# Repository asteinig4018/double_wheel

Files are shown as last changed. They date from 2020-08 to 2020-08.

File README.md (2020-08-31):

# Double Wheel Robot
A completely 3D printed robotics platform with a unique design. 

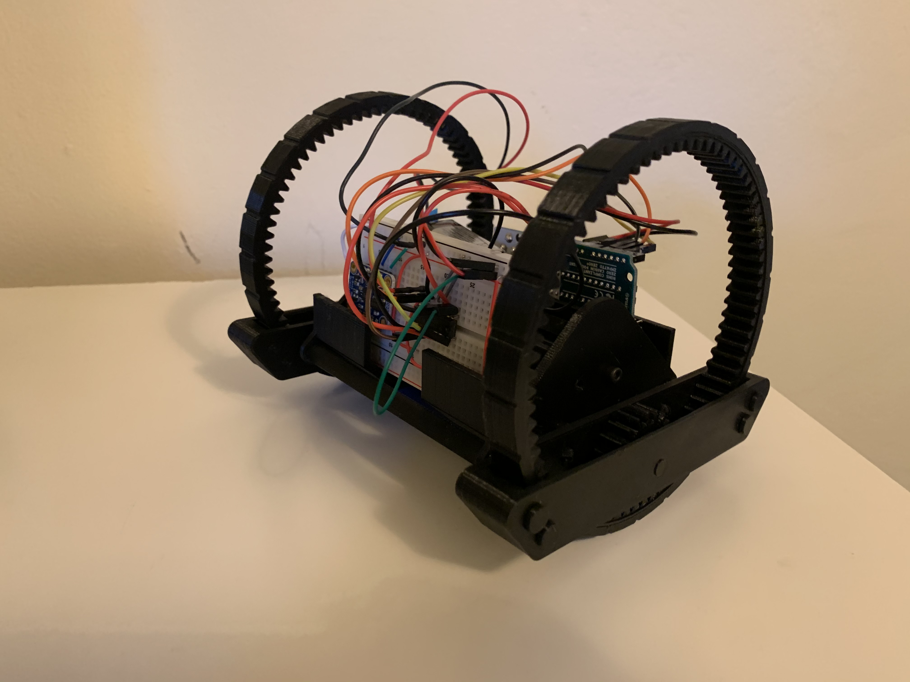
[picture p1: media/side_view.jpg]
Side View V1


## Motivation
This project builds upon the snap fit and gear testing done with my Gearbox Mk1 Project. 
The idea was to create a completely 3D printed platform to experiment with PID control on Arduino in a unique robot body. The large wheels don't provide a whole lot of benefit other than looking unique. 

## Features

### Wheels
The large wheels have 5 points of contact:
- The gear which drives them
- 2 rollers on each side

###image

### Fully 3D Printed Body (almost)
Except for 6 M3-0.5 screws used to hold the motors, the entire body is 3D printed and held together with snap-fits or similar parts.

### Electronics
- On the center breadboard is a BNO055 IMU sensor.
- A L293DNE Quadruple Half H-Bridge is wired up to be 2 full H-Bridges and powers both the left and right motors.

### Motors

## Upgrades

### 12V Battery Pack
Driving the 12V DC motors with between 5V and 9V with the H-bridge proved to be too little voltage. The 12V battery pack uses 8 1.5V AA batteries to provide 12V to the motors.

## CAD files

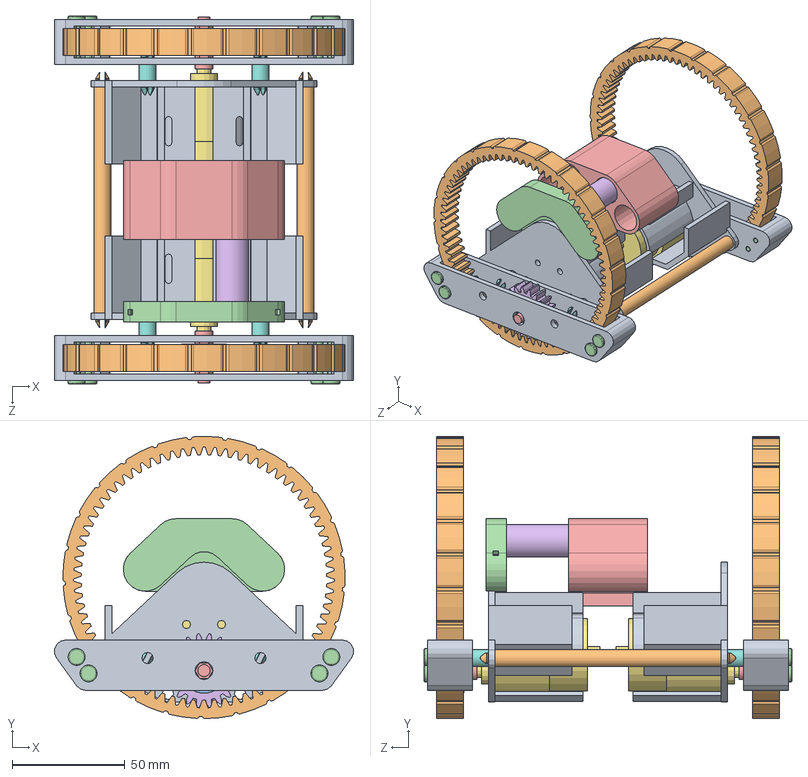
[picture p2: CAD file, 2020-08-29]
full_wheel_asm.SLDASM
132.4 x 125.0 x 163.0 mm
wheel_holder x 2
wheel_v1 x 2
wheel_rollers x 8
roller_pin x 8
wheel_axle x 2
20t_center_gear x 2
Kohree_motor x 2
snap_fastner_short x 4
motor_mount_chasis x 2
snap_fastner_full_length x 2
axle_spacers x 2
battery_endcap
battery_center_support
battery_AA

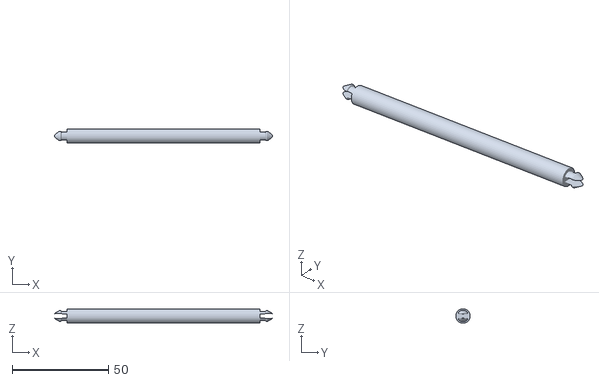
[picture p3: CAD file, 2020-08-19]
stls/snap_fastner_full_length_v1.STL
113.2 x 7.50 x 7.50

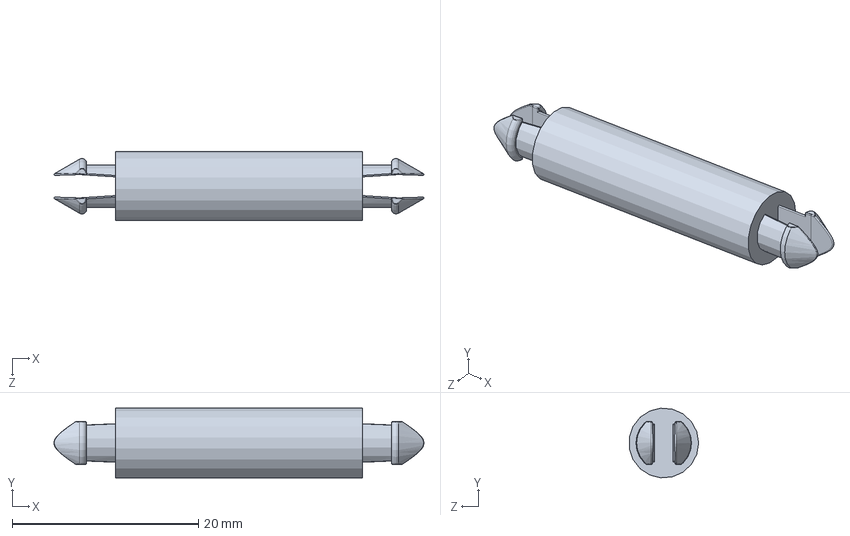
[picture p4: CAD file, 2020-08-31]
snap_fastner_battery.SLDPRT
39.7 x 7.47 x 7.45 mm

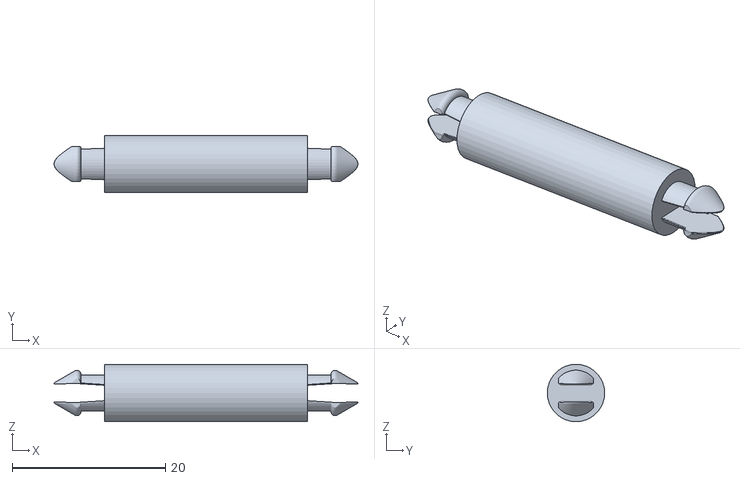
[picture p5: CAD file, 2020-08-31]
stls/snap_fastner_battery_v1.STL
39.7 x 7.50 x 7.50

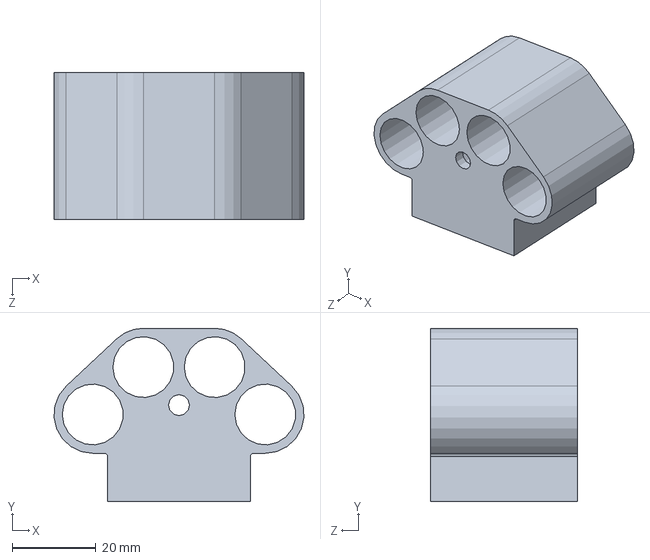
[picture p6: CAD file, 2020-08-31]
battery_center_support.SLDPRT
59.5 x 41.3 x 35.0 mm

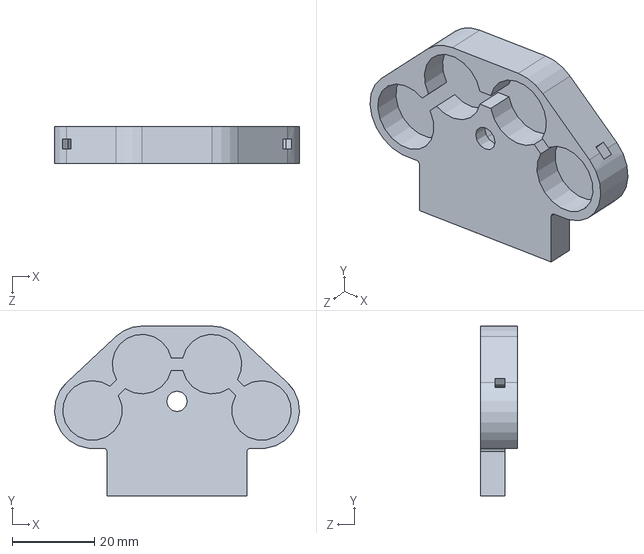
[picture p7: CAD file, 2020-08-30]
battery_endcap.SLDPRT
59.6 x 41.3 x 9.00 mm

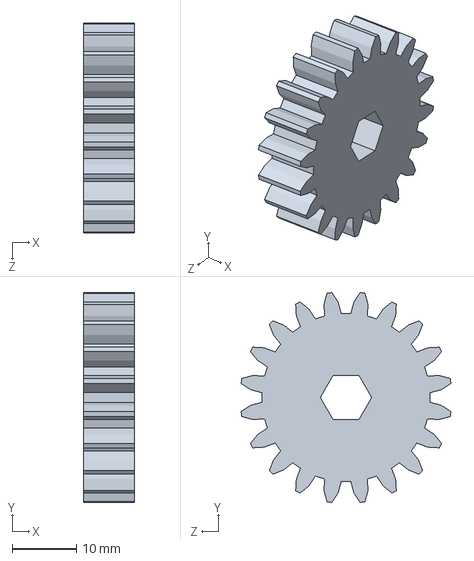
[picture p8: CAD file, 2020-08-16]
20t_center_gear.sldprt
8.00 x 32.7 x 32.7 mm

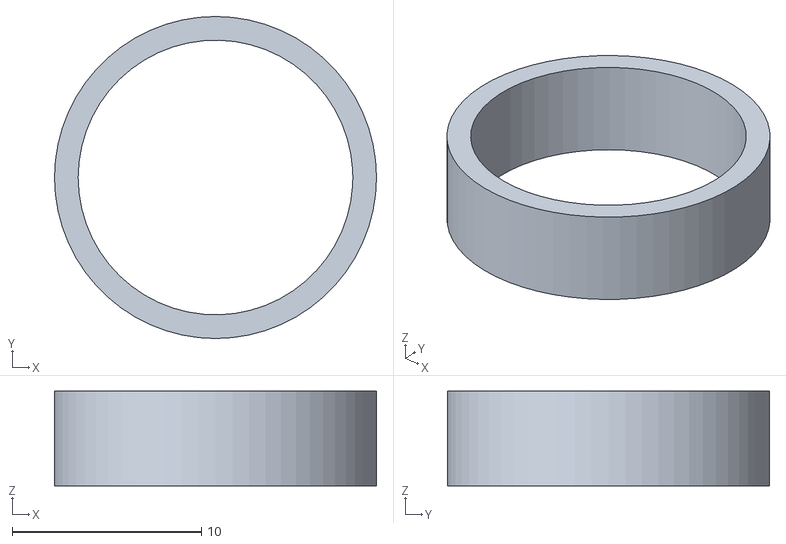
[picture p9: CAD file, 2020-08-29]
stls/battery_tester_v3.STL
17.0 x 17.0 x 5.00

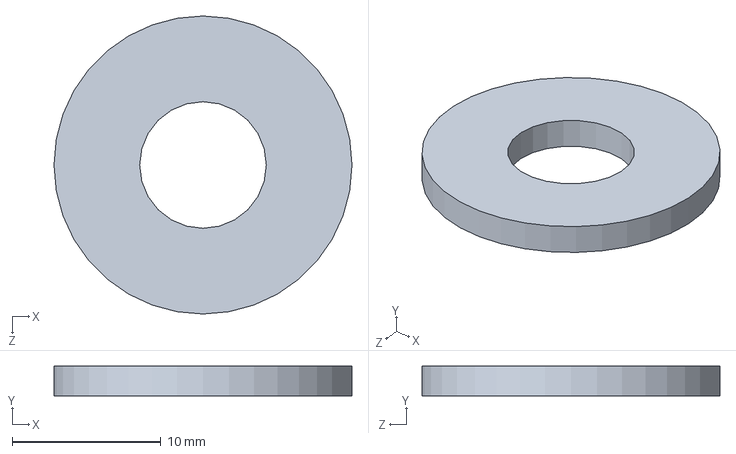
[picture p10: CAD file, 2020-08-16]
axle_spacers.SLDPRT
20.0 x 2.00 x 20.0 mm

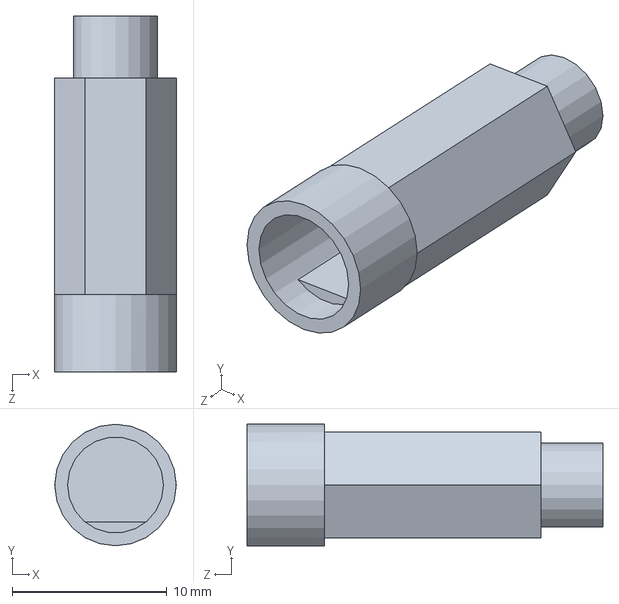
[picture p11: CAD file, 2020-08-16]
wheel_axle.SLDPRT
7.90 x 7.85 x 23.0 mm

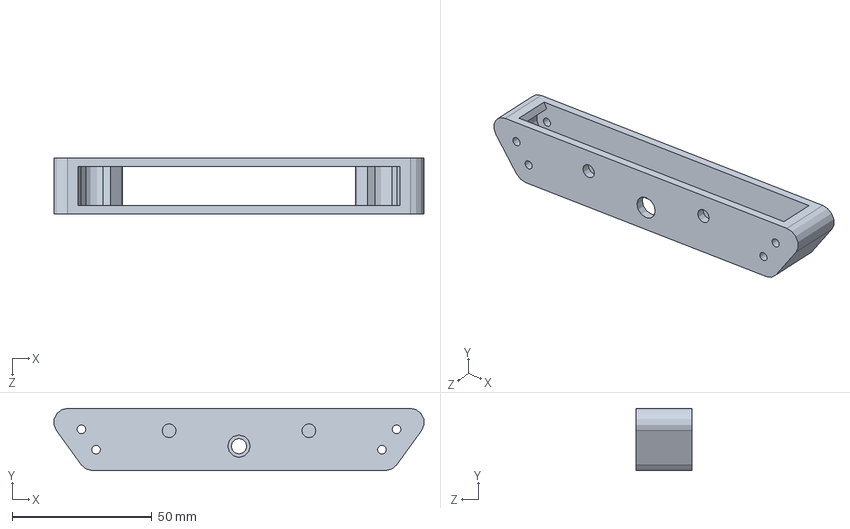
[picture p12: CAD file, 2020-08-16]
wheel_holder.SLDPRT
132.4 x 22.3 x 20.0 mm

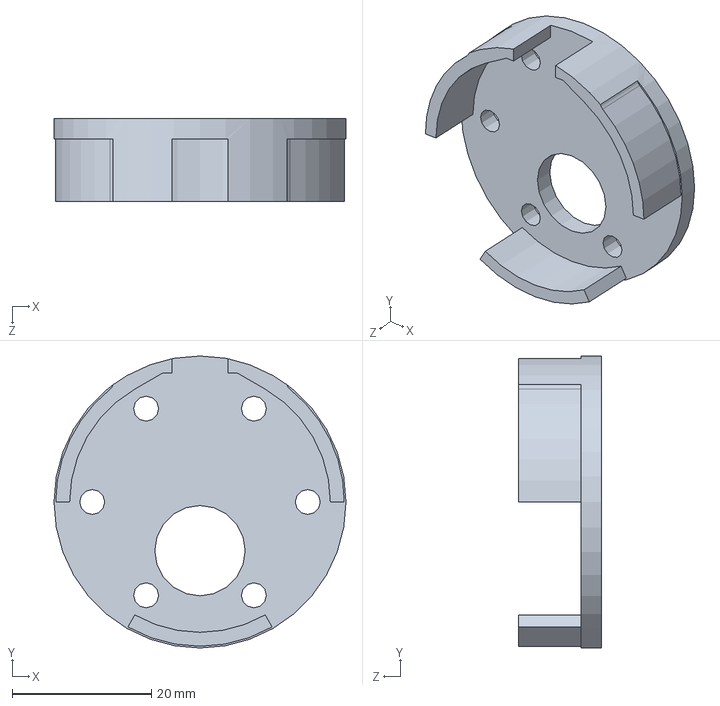
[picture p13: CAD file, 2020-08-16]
motor_test_fit.SLDPRT
42.0 x 42.0 x 12.0 mm

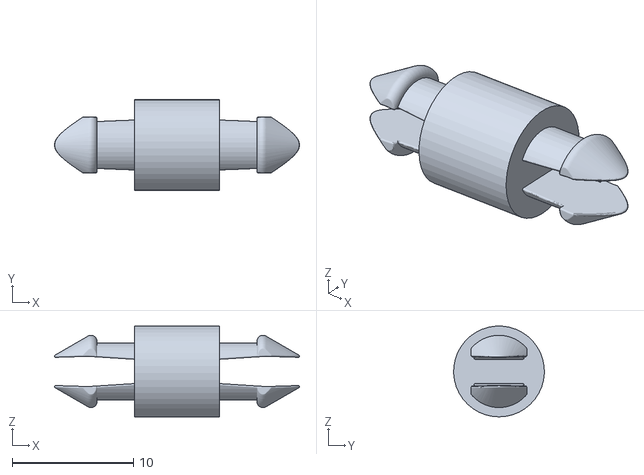
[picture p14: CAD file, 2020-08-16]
stls/snap_fastner_short_v1.STL
20.2 x 7.49 x 7.49

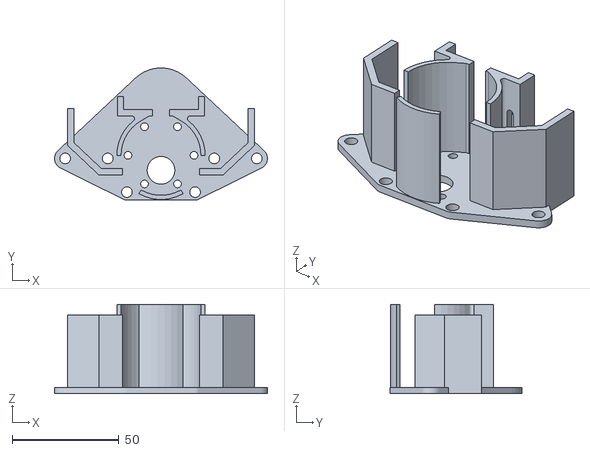
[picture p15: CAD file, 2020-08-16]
stls/motor_mount_chasis_v1.STL
100.0 x 62.0 x 42.0

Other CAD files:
snap_fastner_full_length.SLDPRT
stls/battery_center_support_v1.STL
stls/battery_endcap_v2.STL
wheel_rollers.SLDPRT
Kohree_motor.SLDPRT
motor_mount_chasis.SLDPRT
roller_pin.SLDPRT
snap_fastner_short.SLDPRT
stls/20t_center_gear_v1.STL
stls/20t_center_gear_v2.STL
stls/20t_center_gear_v3.STL
stls/axle_inner_tester.STL
stls/axle_spacers_v1.STL
stls/axle_spacers_v2.STL
stls/axle_tester.STL
stls/battery_endcap_v1.STL
stls/battery_tester.STL
stls/battery_tester_v2.STL
stls/motor_test_fit_v1.STL
stls/motor_test_fit_v2.STL
stls/roller_pin_v1.STL
stls/wheel_axle_v1.STL
stls/wheel_axle_v2.STL
stls/wheel_axle_v3.STL
stls/wheel_axle_v4.STL
stls/wheel_axle_v5.STL
stls/wheel_axle_v6.STL
stls/wheel_holder_v1.STL
stls/wheel_holder_v2.STL
stls/wheel_holder_v3.STL
stls/wheel_rollers_v1.STL
stls/wheel_rollers_v2.STL
stls/wheel_rollers_v3.STL
stls/wheel_rollers_v4.STL
stls/wheel_v1.STL
stls/wheel_v2.STL
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

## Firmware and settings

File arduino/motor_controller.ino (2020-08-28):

const int motor1_dir1_pin = A0;
const int motor1_dir2_pin = A1;

const int motor2_dir1_pin = A2;
const int motor2_dir2_pin = A3;

enum eDirection{
    forward,
    reverse,
    stopped
};

class MController
{
private:
    /* data */
    eDirection ldirection;
    eDirection rdirection;
    int lcurrSpeed;
    int rcurrSpeed;

public:
    MController(/* args */);
    ~MController();
    void both_stop();
    void set_ldirection(eDirection direction);
    void set_rdirection(eDirection direction);
    void set_direction(eDirection direction);
    void incr_left(int numIncr);
    void incr_right(int numIncr);
    void incr_both(int numIncr);
    int get_lSpeed();
    void decr_left(int numDecr);
    void decr_right(int numDecr);
    void decr_both(int numDecr);
};

MController::MController(/* args */)
{
    pinMode(motor1_dir1_pin, OUTPUT);
    pinMode(motor1_dir2_pin, OUTPUT);
    pinMode(motor2_dir1_pin, OUTPUT);
    pinMode(motor2_dir2_pin, OUTPUT);

    ldirection = stopped;
    rdirection = stopped;
    
}

MController::~MController()
{
}

void MController::both_stop(){
    analogWrite(motor1_dir1_pin, 0);
    analogWrite(motor1_dir2_pin, 0);
    analogWrite(motor2_dir1_pin, 0);
    analogWrite(motor2_dir2_pin, 0);

    ldirection = stopped;
    rdirection = stopped;

    lcurrSpeed = 0;
    rcurrSpeed = 0;
}

void MController::set_ldirection(eDirection direction){
    ldirection = direction;
}

void MController::set_rdirection(eDirection direction){
    rdirection = direction;
}

void MController::set_direction(eDirection direction){
    set_ldirection(direction);
    set_rdirection(direction);
}

void MController::incr_left(int numIncr){
    if(ldirection == forward){
        //forward
        lcurrSpeed += numIncr;
        if(lcurrSpeed > 255){
            lcurrSpeed = 255;
        }
        analogWrite(motor1_dir1_pin, lcurrSpeed);
        analogWrite(motor1_dir2_pin, 0);
    }
    else if(ldirection == reverse){
        //reverse
        lcurrSpeed += numIncr;
        if(lcurrSpeed > 255){
            lcurrSpeed = 255;
        }
        analogWrite(motor1_dir1_pin, 0);
        analogWrite(motor1_dir2_pin, lcurrSpeed);
    }
    else{
        //stopped
        analogWrite(motor1_dir1_pin, 0);
        analogWrite(motor1_dir2_pin, 0);
    }
}

void MController::incr_right(int numIncr){
    if(rdirection == forward){
        //forward
        rcurrSpeed += numIncr;
        if(rcurrSpeed > 255){
            rcurrSpeed = 255;
        }
        analogWrite(motor2_dir1_pin, rcurrSpeed);
        analogWrite(motor2_dir2_pin, 0);
    }
    else if(rdirection == reverse){
        //reverse
        rcurrSpeed += numIncr;
        if(rcurrSpeed > 255){
            rcurrSpeed = 255;
        }
        analogWrite(motor2_dir1_pin, 0);
        analogWrite(motor2_dir2_pin, rcurrSpeed);
    }
    else{
        analogWrite(motor2_dir1_pin, 0);
        analogWrite(motor2_dir2_pin, 0);
    }
}

void MController::incr_both(int numIncr){
    incr_left(numIncr);
    incr_right(numIncr);
}

int MController::get_lSpeed(){
    return lcurrSpeed;
}

void MController::decr_left(int numDecr){
    if(ldirection == forward){
        //forward
        lcurrSpeed -= numDecr;
        if(lcurrSpeed < 0){
            lcurrSpeed = 0;
        }
        analogWrite(motor1_dir1_pin, lcurrSpeed);
        analogWrite(motor1_dir2_pin, 0);
    }
    else if(ldirection == reverse){
        //reverse
        lcurrSpeed -= numDecr;
        if(lcurrSpeed < 0){
            lcurrSpeed = 0;
        }
        analogWrite(motor1_dir1_pin, 0);
        analogWrite(motor1_dir2_pin, lcurrSpeed);
    }
    else{
        //stopped
        analogWrite(motor1_dir1_pin, 0);
        analogWrite(motor1_dir2_pin, 0);
    }
}

void MController::decr_right(int numDecr){
    if(rdirection == forward){
        //forward
        rcurrSpeed -= numDecr;
        if(rcurrSpeed < 0){
            rcurrSpeed = 0;
        }
        analogWrite(motor2_dir1_pin, rcurrSpeed);
        analogWrite(motor2_dir2_pin, 0);
    }else if(rdirection == reverse){
        //reverse
        rcurrSpeed -= numDecr;
        if(rcurrSpeed < 0){
            rcurrSpeed = 0;
        }
        analogWrite(motor2_dir1_pin, 0);
        analogWrite(motor2_dir2_pin, rcurrSpeed);
    }
    else{
        //stopped
        analogWrite(motor2_dir1_pin, 0);
        analogWrite(motor2_dir2_pin, 0);
    }
}

void MController::decr_both(int numDecr){
    decr_left(numDecr);
    decr_right(numDecr);
}

MController mcontroller;

void setup(){

    //Serial.begin(115200);
    
    mcontroller.both_stop();
    mcontroller.set_direction(forward);

    

}


void loop(){
    mcontroller.set_direction(forward);
    mcontroller.incr_both(250);
    delay(5000);
    mcontroller.both_stop();
    delay(1000);
    mcontroller.set_direction(reverse);
    mcontroller.incr_both(250);
    delay(5000);
    mcontroller.both_stop();
    delay(1000);
    mcontroller.set_direction(forward);
    //mcontroller.incr_left(160);
    mcontroller.incr_right(250);
    delay(5000);
    mcontroller.both_stop();
    delay(1000);

}

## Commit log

2020-08-08 initial commit with two wheel parts
    [wheel_holder.SLDPRT, wheel_v1.SLDPRT]
2020-08-08 created full asembly with wheel rollers
    [full_wheel_asm.SLDASM, wheel_holder.SLDPRT, wheel_rollers.SLDPRT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]
2020-08-08 made center gear independent to modify
    [20t_center_gear.sldprt, full_wheel_asm.SLDASM]
2020-08-08 added roller pins
    [full_wheel_asm.SLDASM, roller_pin.SLDPRT]
2020-08-08 added wheel axle
    [20t_center_gear.sldprt, full_wheel_asm.SLDASM, wheel_axle.SLDPRT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]
2020-08-08 first batch of stls for testing
    [20t_center_gear_v1.STL, roller_pin_v1.STL, wheel_axle_v1.STL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]
2020-08-12 possible motor
    [Kohree_motor.SLDPRT]
2020-08-12 fastner added
    [snap_fastner_short.SLDPRT]
2020-08-12 closer to full build using motor
    [20t_center_gear.sldprt, full_wheel_asm.SLDASM, motor_mount_chasis.SLDPRT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]
2020-08-12 added indent to reduce catching on chassis, at least on one side
    [wheel_v1.SLDPRT]
2020-08-13 added mounting location for battery and boards
    [full_wheel_asm.SLDASM, motor_mount_chasis.SLDPRT]
2020-08-13 added stls including new part to test motor fit
    [20t_center_gear_v2.STL, motor_test_fit.SLDPRT, motor_test_fit_v1.STL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]
2020-08-13 new parts to test axle engagement
    [axle_tester.STL, wheel_axle.SLDPRT, wheel_axle_v3.STL]
2020-08-14 increased hole dimension for roller
    [wheel_rollers_v2.STL]
2020-08-14 fixed some dimensions
    [wheel_holder_v3.STL, wheel_rollers_v3.STL]
2020-08-15 more stls
    [wheel_axle_v4.STL, wheel_rollers_v4.STL]
2020-08-15 more tester parts
    [axle_inner_tester.STL, motor_test_fit_v2.STL]
2020-08-15 new tester axle part
    [axle_inner_tester.STL]
2020-08-15 new axle tester part with flat
    [axle_inner_tester.STL]
2020-08-15 hopefully final wheel axle
    [wheel_axle_v5.STL]
2020-08-15 account for non flat part
    [wheel_axle_v6.STL]
2020-08-15 new gear
    [20t_center_gear_v3.STL]
2020-08-16 added initial arduino code
2020-08-16 new spacer
    [axle_spacers_v1.STL]
2020-08-16 various improvements with new measurements from test parts
    [20t_center_gear.sldprt, axle_spacers.SLDPRT, full_wheel_asm.SLDASM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]
2020-08-16 more motor controller functions
2020-08-16 round hole for axle spacer
    [axle_spacers.SLDPRT, axle_spacers_v2.STL]
2020-08-16 stl for main chassis
    [20t_center_gear.sldprt, full_wheel_asm.SLDASM, motor_mount_chasis_v1.STL]
2020-08-16 added tester coded and added to the motor contorller class
2020-08-16 added snap fastner
    [snap_fastner_short_v1.STL]
2020-08-19 added stl for main cross beam
    [snap_fastner_full_length_v1.STL]
2020-08-29 new parts for 12v battery pack
    [battery_center_support.SLDPRT, battery_endcap.SLDPRT]
2020-08-29 changed size of end cap and added middle part
    [battery_center_support.SLDPRT, battery_endcap.SLDPRT, full_wheel_asm.SLDASM]
2020-08-29 test part for batter diameter
    [battery_endcap.SLDPRT, battery_tester.STL]
2020-08-29 wrong dimension
    [battery_tester_v2.STL]
2020-08-29 new dimension to test
    [battery_tester_v3.STL]
2020-08-29 changed battery grip dimension
    [battery_center_support.SLDPRT, battery_endcap.SLDPRT, battery_endcap_v1.STL]
2020-08-30 endcap change based on first print
    [battery_endcap.SLDPRT, battery_endcap_v2.STL]
2020-08-31 center support stl
    [battery_center_support_v1.STL]
2020-08-31 added battery snap fastener
    [battery_center_support.SLDPRT, snap_fastner_battery.SLDPRT, snap_fastner_battery_v1.STL]
2020-08-31 added part about 3d printed body
